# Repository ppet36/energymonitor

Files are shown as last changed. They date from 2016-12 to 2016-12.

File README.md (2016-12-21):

# Energy Monitor

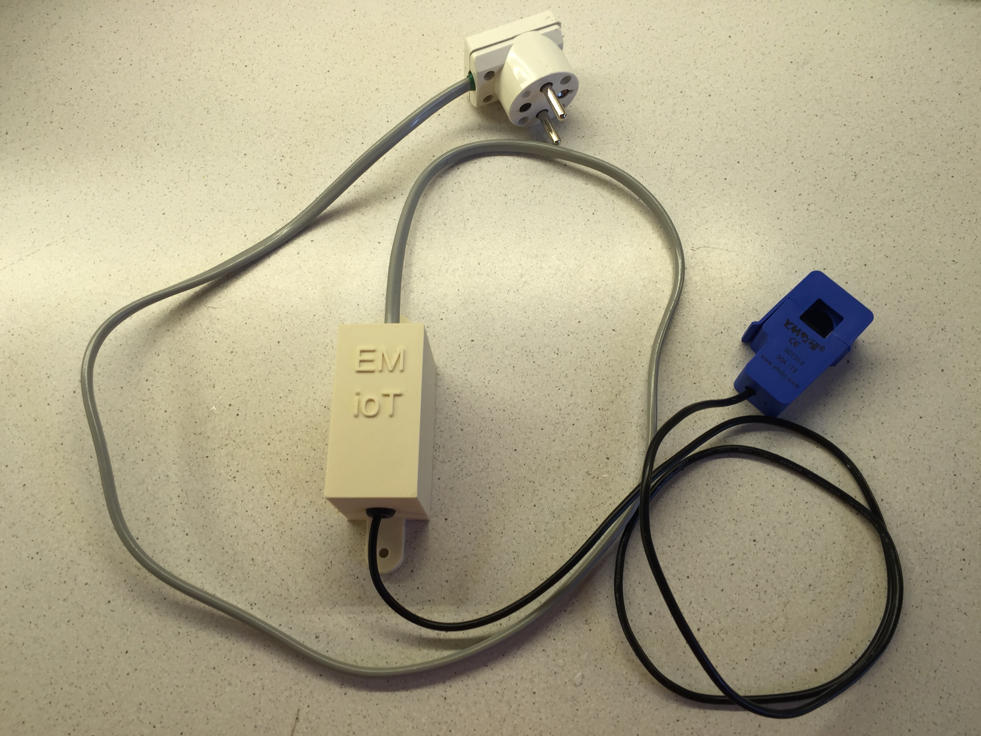
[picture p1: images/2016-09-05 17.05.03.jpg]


This repository encapsulates one phase energy monitor for ThingSpeak based on ESP8266-01 module, current transformer and precision rectifier.

Because ESP8266-01 has only two digital I/O pins (and also for resolution) is for A/D conversion used 18bit I2C A/D converter MCP3421 and fullwave precision rectifier realized via double operational amplifier LM258. For measuring current is used current transformer 30A SCT-013-030 which has already integrated shunt resistor.

For powering is used miniature 3.3V/600mA power supply from eBay such as http://www.ebay.com/itm/400761809788, but due to initial power requirements of ESP8266 i recomend 3.3V/1A power supply (which is also available through this seller).

Repository contains CadSoft's Eagle schematic and PCB layout. Because i do not have equipment for proper handling of SMDs (and also for use MCP3421 on breadboard) i created small DPS that holds MCP3421 and has standard DIP dimensions.
Note: Some 100n capacitors is soldered directly to pins on bottom side of PCB.

Software can be uploaded to ESP8266 via Arduino IDE. For building you need MCP342x module which is available here https://github.com/uChip/MCP342X on GitHub. For first 5 minutes after module startup is available WiFi AP "EnergyMonitor" with HTTP server at 192.168.4.1:80 behind it. On this URL is available simple configuration page for setting WiFi parameters, ThingSpeak channel/field with write-key, mains voltage and other tunning parameters. After 5 minutes, when the page is not accessed, module starts automatically. After module connects to configured WiFi is configuration server available on internal network at DHCP assigned IP address. Default parameters can be set in source file.

There are also OpenSCAD and STL model for enclosure.

I use module for several months at home and also on cottage. My public channels on ThingSpeak are:

https://thingspeak.com/channels/150525

https://thingspeak.com/channels/157732

Here are some project images:

### PCBs
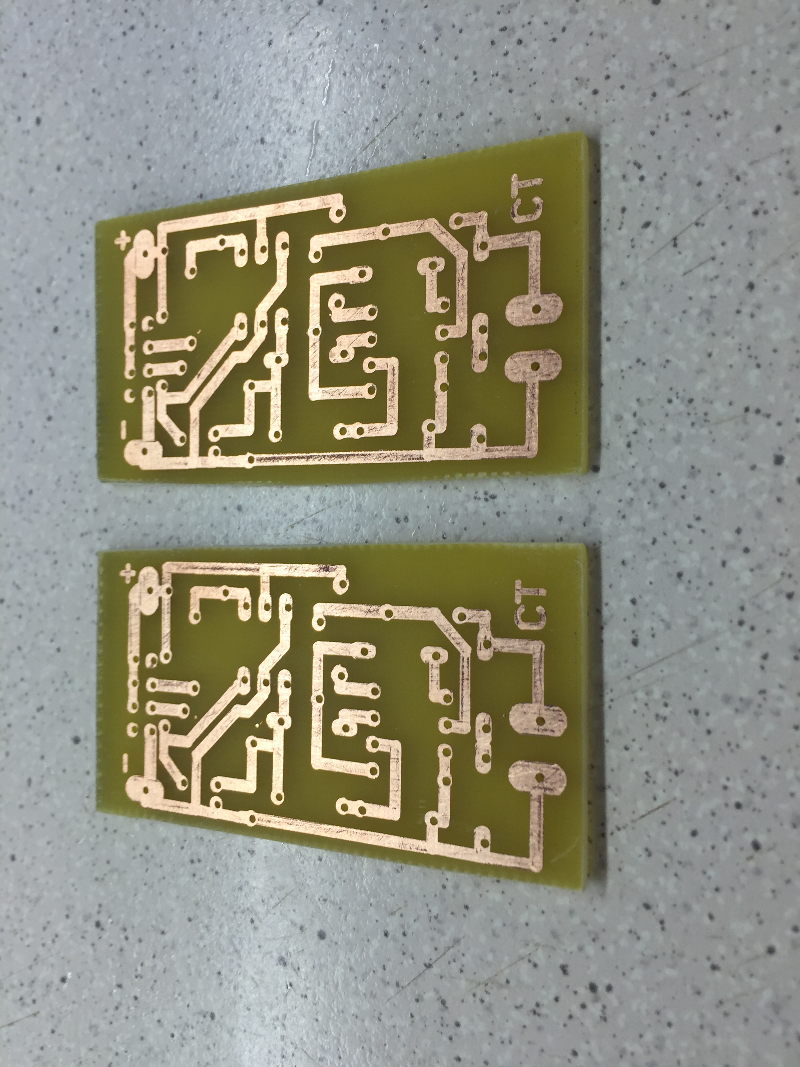
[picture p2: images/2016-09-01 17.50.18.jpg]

### Mounted PCB
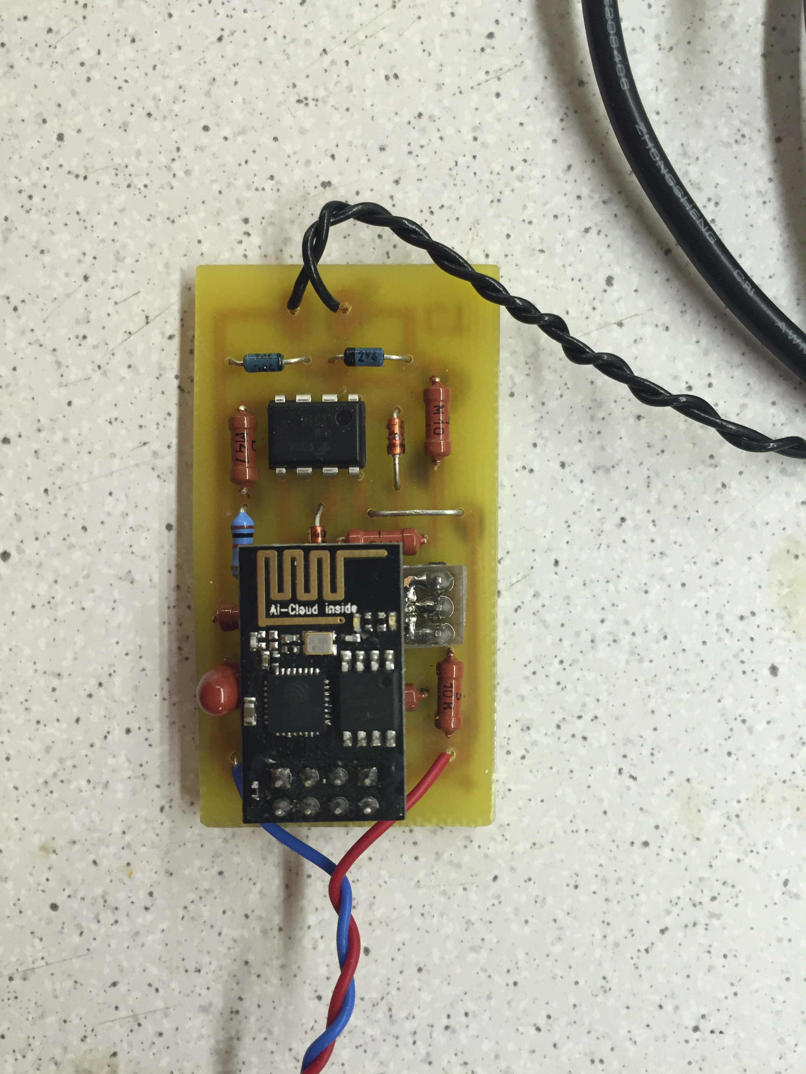
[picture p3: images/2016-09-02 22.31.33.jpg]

### 3D printed case
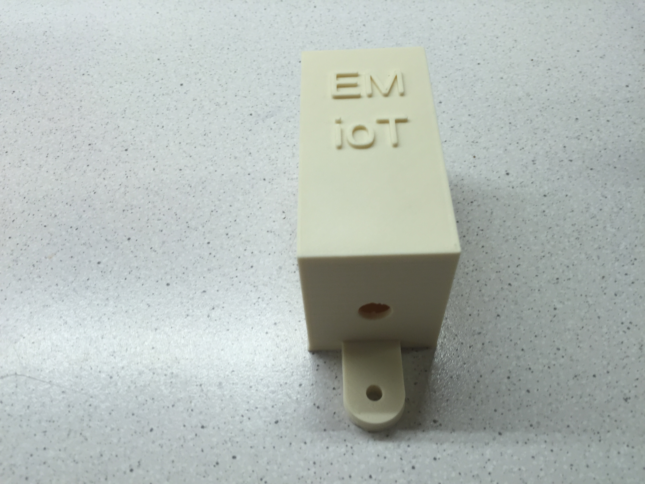
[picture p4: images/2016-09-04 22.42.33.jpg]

### MCP3421 breadboard modules
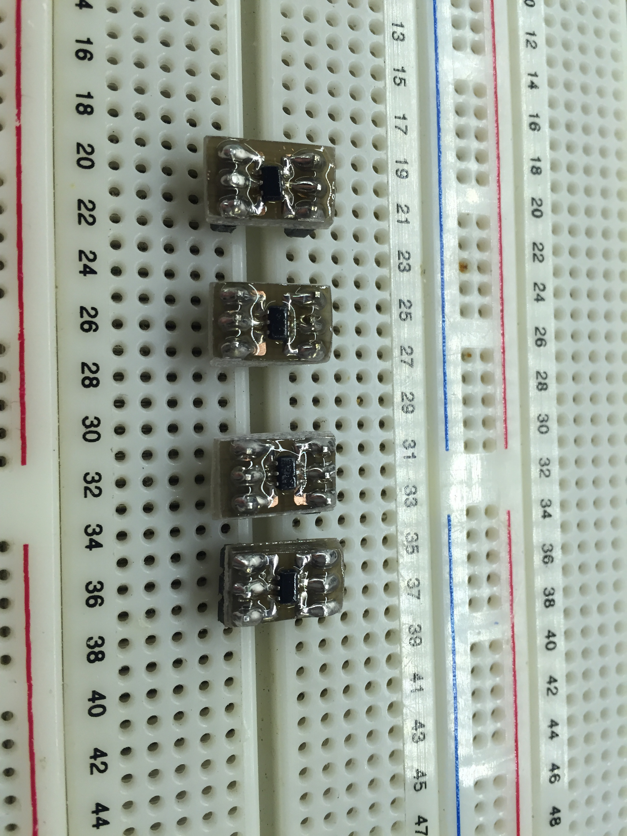
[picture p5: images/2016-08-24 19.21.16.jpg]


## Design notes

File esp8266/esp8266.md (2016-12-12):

ESP8266 software for uploading via Arduino IDE.

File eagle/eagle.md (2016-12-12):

This directory contains schematic, PCB layout for Eagle.

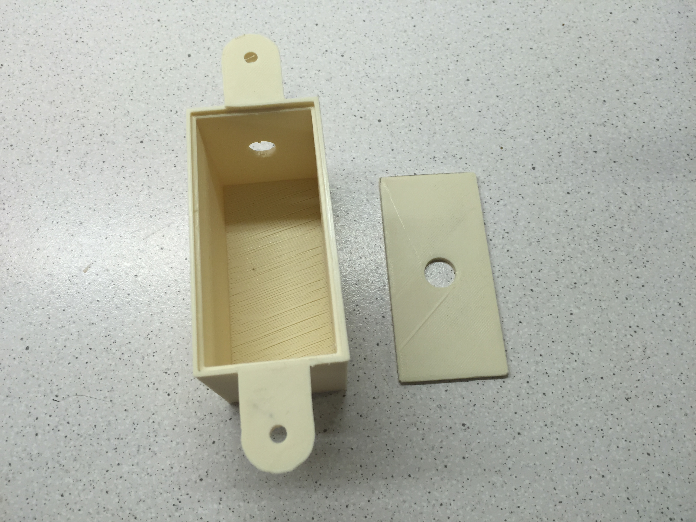
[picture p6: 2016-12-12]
images/2016-09-04 22.43.05.jpg

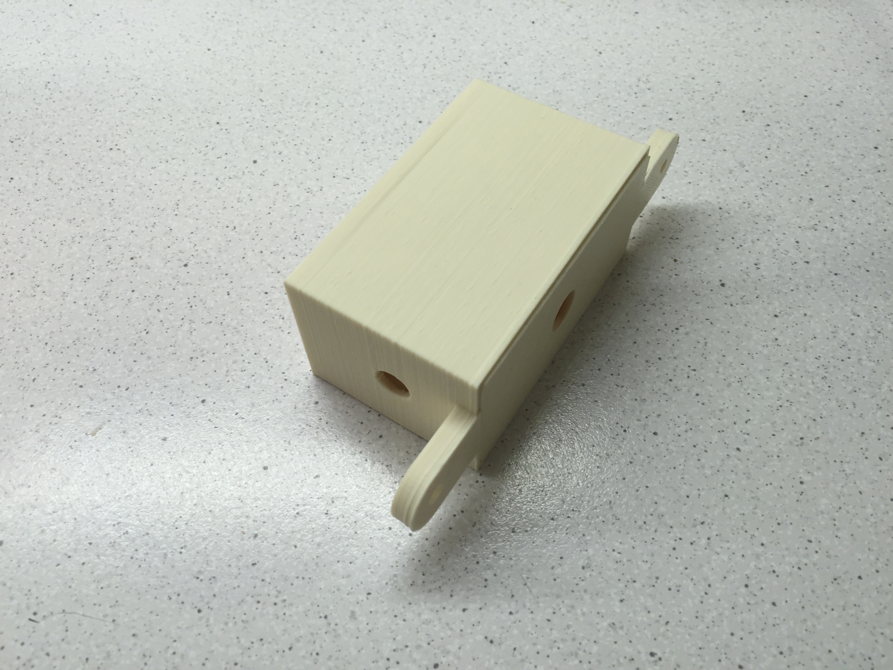
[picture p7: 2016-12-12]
images/2016-09-04 22.42.39.jpg

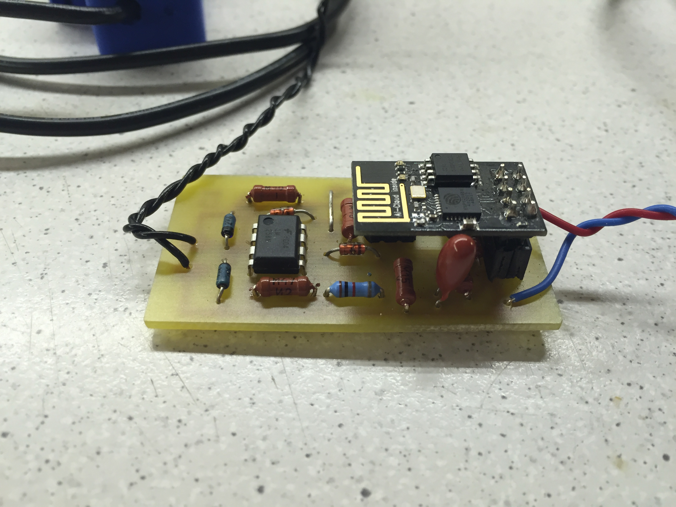
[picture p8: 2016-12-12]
images/2016-09-02 22.33.28.jpg

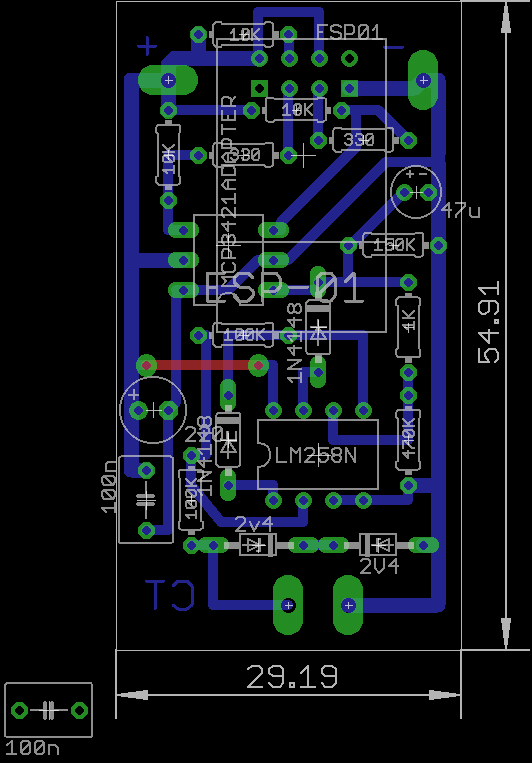
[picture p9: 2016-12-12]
eagle/energy_monitor_brd.png

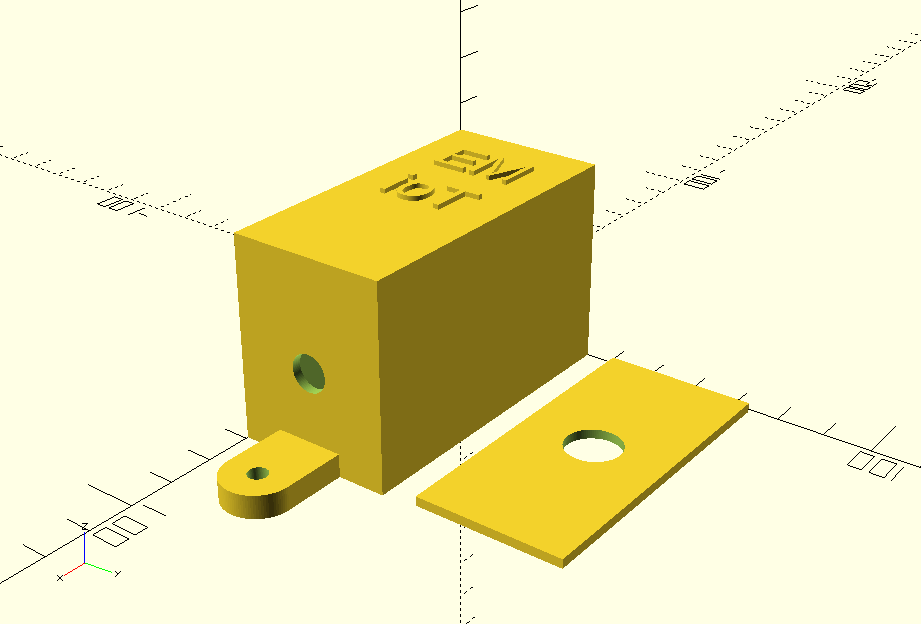
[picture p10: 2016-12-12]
openscad/case.png

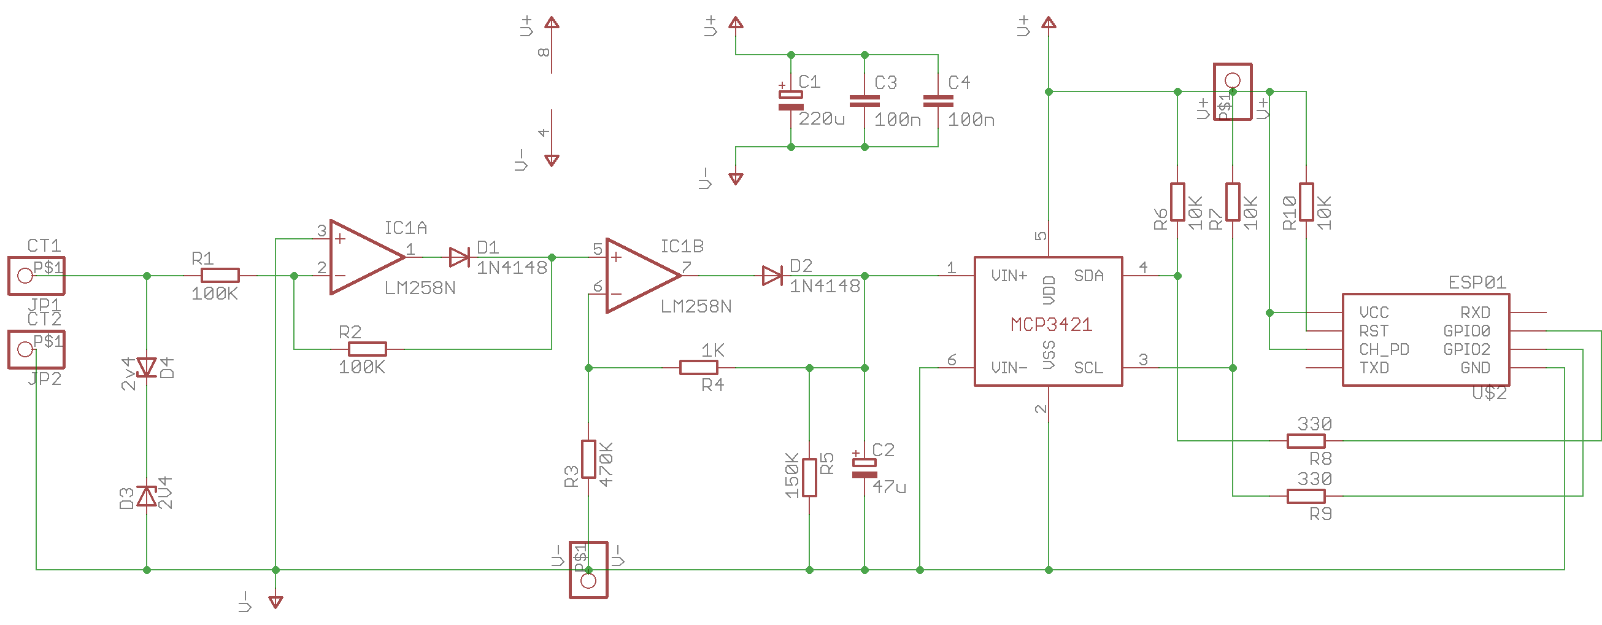
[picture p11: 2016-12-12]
eagle/energy_monitor_sch.png

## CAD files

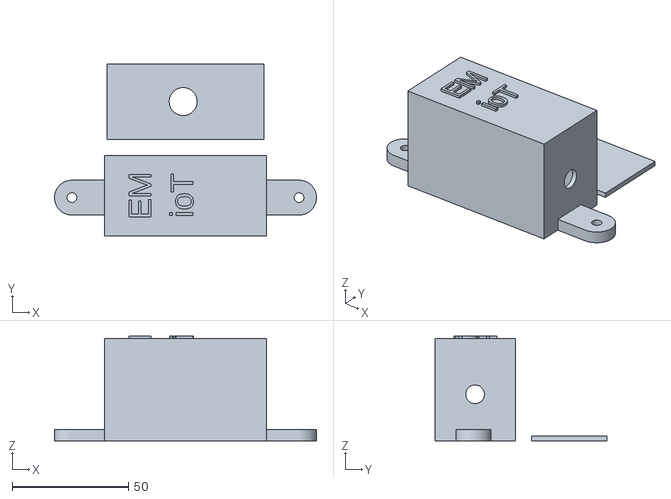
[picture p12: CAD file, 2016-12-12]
openscad/energy_monitor.stl
112.5 x 73.9 x 45.0

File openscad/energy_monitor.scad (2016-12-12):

innerWidth = 65.5;
innerHeight = 30.5;
innerDepth = 40;
thickness = 2;

$fn=100;

module box() {
  union() {
    difference() {
      cube ([innerWidth + 2*thickness, innerHeight+2*thickness, innerDepth + 2*thickness]);
      translate ([thickness,thickness,0]) cube ([innerWidth, innerHeight, innerDepth]);
      translate([innerWidth/2+thickness,(innerHeight+2*thickness)/2,(innerDepth/2)]) rotate([0,90,0]) cylinder (d=8,h=innerWidth+2*thickness,center=true);
    }
    
    color("red") translate([20,7,innerDepth+thickness]) rotate([0,0,90]) linear_extrude (height=3) text ("EM");
    color("red") translate([38,8,innerDepth+thickness]) rotate([0,0,90]) linear_extrude (height=3) text ("ioT");
  }
}

module ousko() {
  difference() {
    hull() {
      cylinder (d=15,h=5, center=true);
      translate([8,0,0]) cube ([15, 15, 5], center=true);
    }
    cylinder (d=4.2,h=5, center=true);
  }
}

module vrsek() {
  difference() {
    union() {
      box();
      translate ([-14,16.5,2.5]) ousko();
      translate ([innerWidth+14+thickness*2,16.5,2.5]) rotate ([0,0,180]) ousko();
    }
    vicko();
  }
}

module vicko() {
  color("green") {
    difference() {
      translate([thickness/2,thickness/2,0]) cube ([innerWidth + thickness-0.1, innerHeight+thickness-0.1, thickness]);
      translate([thickness/2+innerWidth/2,thickness/2+innerHeight/2+1,0])cylinder (d=12,h=thickness);
    }
  }
}

vrsek();
translate ([0,innerHeight+10,0]) vicko();

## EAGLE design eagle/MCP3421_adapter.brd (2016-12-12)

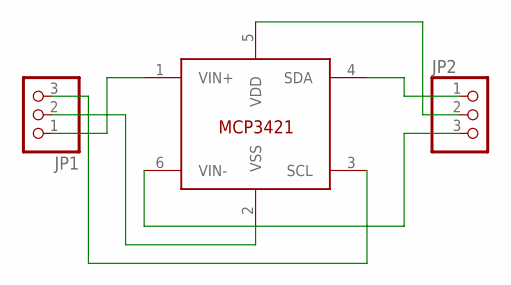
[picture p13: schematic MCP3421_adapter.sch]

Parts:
JP1, JP2: PINHD-1X3; 1X03
U$1: MCP3421; SOT23-6

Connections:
unnamed: JP1.1, U$1.1 (VIN+)
unnamed: JP1.2, U$1.2 (VSS)
unnamed: JP1.3, U$1.3 (SCL)
unnamed: JP2.1, U$1.4 (SDA)
unnamed: JP2.2, U$1.5 (VDD)
unnamed: JP2.3, U$1.6 (VIN-)

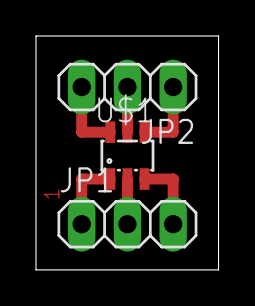
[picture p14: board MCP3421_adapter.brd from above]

Board: 2 copper layers, 10.1 x 13.0 mm, 3 parts (0 on the bottom side), 6 nets.

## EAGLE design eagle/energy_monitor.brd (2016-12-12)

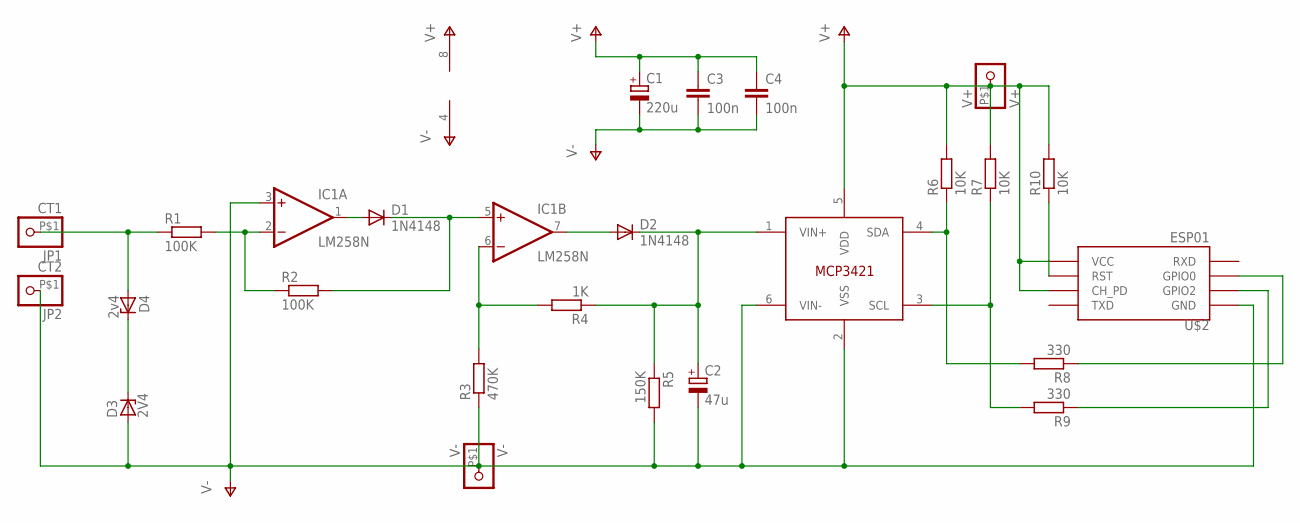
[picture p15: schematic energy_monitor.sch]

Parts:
C1: 220u; E2,5-6
C2: 47u; E2-4
C3, C4: 100n; C050-045X075
D1, D2: 1N4148; DO35-7
D3: 2V4; DO34Z7
D4: 2v4; DO34Z7
IC1: LM258N; DIL08
JP1: CT1; 1X1-BIGPOGO
JP2: CT2; 1X1-BIGPOGO
R1, R2: 100K; 0204/7
R3: 470K; 0204/7
R4: 1K; 0204/7
R5: 150K; 0204/7
R6, R7, R10: 10K; 0204/7
R8, R9: 330; 0204/7
U$1: MCP3421ADAPTER; DIL06
U$2: ESP01
V+: V+; 1X1-BIGPOGO
V-: V-; 1X1-BIGPOGO

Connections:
unnamed: D4.A, JP1.P$1, R1.1
unnamed: IC1.2 (-IN), R1.2, R2.1
unnamed: D1.A, IC1.1 (OUT)
unnamed: D1.C, IC1.5 (+IN), R2.2
unnamed: D3.C, D4.C
unnamed: D2.A, IC1.7 (OUT)
unnamed: C2.+, D2.C, R4.1, R5.1, U$1.1 (VIN+)
unnamed: IC1.6 (-IN), R3.2, R4.2
unnamed: R6.1, R8.2, U$1.4 (SDA)
unnamed: R7.1, R9.2, U$1.3 (SCL)
unnamed: R10.1, U$2.RST
unnamed: R8.1, U$2.GPIO0
unnamed: R9.1, U$2.GPIO2
V+: C1.+, C3.1, C4.1, IC1.8 (V+), R6.2, R7.2, R10.2, U$1.5 (VDD), U$2.CH_PD, U$2.VCC, V+.P$1
V-: C1.-, C2.-, C3.2, C4.2, D3.A, IC1.3 (+IN), IC1.4 (V-), JP2.P$1, R3.1, R5.2, U$1.2 (VSS), U$1.6 (VIN-), U$2.GND, V-.P$1

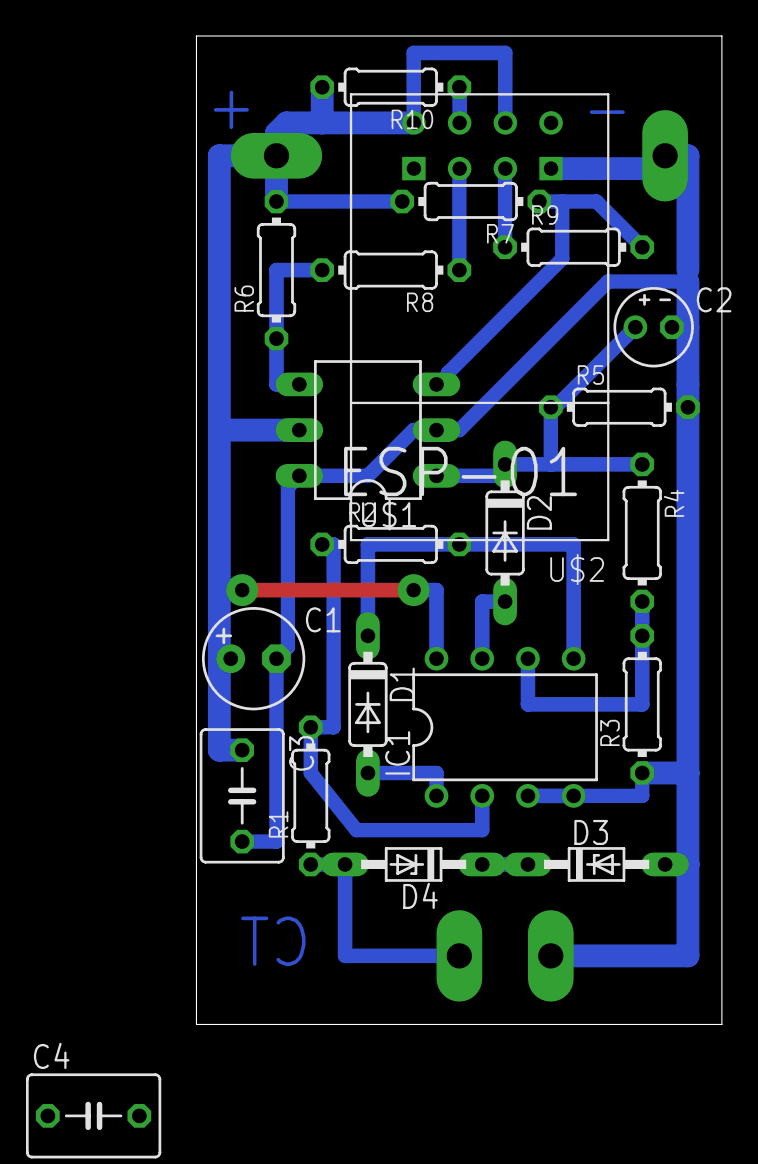
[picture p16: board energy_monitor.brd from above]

Board: 2 copper layers, 29.2 x 54.9 mm, 25 parts (0 on the bottom side), 15 nets.

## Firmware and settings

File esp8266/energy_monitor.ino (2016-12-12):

#include <Wire.h>
#include <MCP342x.h>
#include <EEPROM.h>
#include <ESP8266WiFi.h>
#include <ESP8266HTTPClient.h>
#include <WiFiClient.h>
#include <ESP8266WiFiMulti.h>
#include <ESP8266WebServer.h>

/**
 * One phase energy monitor based on ESP8266, MCP3421.
 * 
 * @author Pavel Petrzela
*/

// Magic, abych poznal, jestli jsem zapsal do EEPROM ja
#define MAGIC 0xA6

// Timeout konfigurace
#define CONFIG_TIMEOUT 1000 * 60 * 5

// Nazev WIFI AP
#define WIFI_AP_SSID "EnergyMonitorAP"

// Timeout A/D konverze
#define AD_TIMEOUT 2000

// Port WEB serveru konfigurace
#define WEB_SERVER_PORT 80

// Maximalni pocet vzorku do odeslani
#define MAX_SAMPLE_FREQUENCY 256

// Maximalni pocet radku v logu
#define MAX_LOG_LINES 50

// Maximalni index fieldu na ThingSpeak
#define TS_MAX_FIELD 8

// adresa MCP3421 A/D prevodniku
const uint8_t address = 0x68;

// Komunikacni objekt
MCP342x adc = MCP342x (address);

// Wifi
ESP8266WiFiMulti wifiMulti;

// Struktura do EEPROM
struct EmConfiguration {
  int magic;
  int sampleFrequency;
  char apName [24];
  char password [48];
  long voltage;
  long offset;
  long divider;
  char tsWriteKey [20];
  int tsFieldId;
};

// Nastaveni
EmConfiguration config;

// Server pro konfiguraci
ESP8266WebServer *server;

// Priznak, zdali byla spustena konfigurace
bool configExecuted = false;

// Posledni interakce s konfiguraci
long lastInteractionTime;

// Seznam radku logu
String logLines [MAX_LOG_LINES];
int logLinesIndex = 0;

// Posledni status
String lastStatus;

/**
 * Metoda je provedena pri inicializaci.
*/
void setup(void) {
  Serial.begin (115200);
  // Vypneme WiFi, aby se to nazacatek o nic nepokouselo
  WiFi.mode (WIFI_OFF);

  delay (10000);

  int i;
  for (i = 0; i < MAX_LOG_LINES; i++) {
    logLines [i] = "";
  }

  emLogLine ("setup()");

  // Komunikace po i2c sbernici na pinech 0 (sda) a 2 (scl)
  Wire.begin (0, 2);

  // Zkusime najit MCP3421
  do {
    emLogLine ("I2C reset...");
    // Reset sbernice
    MCP342x::generalCallReset();
    delay (10);

    emLogLine ("Searching MCP3421...");
  
    // Zjistime, zdali je MCP3421 na sbernici
    Wire.requestFrom (address, (uint8_t)1);
    if (!Wire.available()) {
      emLog ("No MCP3421 found at address ");
      emLogLine (String(address));
      delay (5000);
    } else {
      break;
    }
  } while (1);

  emLogLine ("MCP3421 found... reading configuration from EEPROM...");

  // nacteni konfigurace; pokud konfigurace jeste nebyla
  // vytvorena, tak se vymaze a inicializuje defaultnimi
  // hodnotami
  EEPROM.begin (sizeof (EmConfiguration));
  EEPROM.get (0, config);

  if (config.magic != MAGIC) {
    memset (&config, 0, sizeof (EmConfiguration));
    config.magic = MAGIC;
    config.sampleFrequency = 50;
    config.voltage = 230;
    config.offset = 523L;
    config.divider = 3805L;
    config.tsFieldId = 1;
    EEPROM.put (0, config);
  }
  
  EEPROM.end();

  emLog ("Configuration readed .. starting AP ");
  emLogLine (WIFI_AP_SSID);

  // Spustime konfiguracni AccessPoint pod nazvem EnergyMonitorAP
  WiFi.softAP (WIFI_AP_SSID);

  // ... a spustime HTTP server pro nastaveni; konfiguracni server
  // pobezi 5 minut od spusteni, pak 
  server = new ESP8266WebServer (WiFi.softAPIP(), WEB_SERVER_PORT);
  server->on ("/", wsHandleRoot);
  server->on ("/update", wsHandleUpdate);
  server->on ("/run", wsHandleRun);
  server->on ("/log", wsDisplayLog);
  server->on ("/getAdc", wsGetAdc);
  server->begin();

  emLog ("Started WebServer at ");
  emLog (ipToString (WiFi.softAPIP()));
  emLogLine (" port 80...");

  lastInteractionTime = millis();
  lastStatus = "";
}

/**
 * Prevede IP adresu do retezce.
*/
String ipToString (IPAddress myIP) {
  return String(myIP[0])+"."+String(myIP[1])+"."+String(myIP[2])+"."+String(myIP[3]);
}

/**
 * Prida radek do logu.
 * 
 * @param line radek.
*/
void emLogLine (String line) {
  if (logLinesIndex >= MAX_LOG_LINES - 1) {
    logLines [logLinesIndex] += line;
    
    int i;
    for (i = 1; i < MAX_LOG_LINES; i++) {
      logLines [i - 1] = logLines [i];
    }

    logLines [MAX_LOG_LINES - 1] = "";
  } else {
    logLines [logLinesIndex++] += line;
  }

  Serial.println (line);
}

/**
 * Pripoji retezec za posledni radek logu.
 * 
 * @param str retezec.
*/
void emLog (String str) {
  if (logLinesIndex >= MAX_LOG_LINES - 1) {
    logLines [MAX_LOG_LINES - 1] += str;
  } else {
    logLines [logLinesIndex] += str;
  }

  Serial.print (str);
}

/**
 * Aktualizuje retezcovou promennou v konfiguraci na zaklade
 * predaneho retezce.
 *
 * @param c promenna.
 * @param len maximalni delka.
 * @param val arduino string pro prevedeni.
*/
void updateConfigKey (char *c, int len, String val) {
  memset (c, 0, len);
  sprintf (c, "%s", val.c_str());
}

/**
 * Zapise koren http serveru; konfiguracni obrazovku.
*/
void wsHandleRoot() {
  String resp = "<html><head><title>Energy monitor configuration</title>";
  resp += "<meta name=\"viewport\" content=\"initial-scale=1.0, width = device-width, user-scalable = no\">";
  resp += "<script>";
  resp += "function ebi(s) {";
  resp += "return document.getElementById (s);";
  resp += "}\n";
  resp += "function updateAdc() {";
  resp += "var xhttp = new XMLHttpRequest();";
  resp += "xhttp.onreadystatechange = function() {";
  resp += "  if ((this.readyState == 4) && (this.status == 200)) {";
  resp += "    var adcVal = parseInt (this.responseText);";
  resp += "    var form = ebi('form');";
  resp += "    var voltage = parseInt (form.voltage.value);";
  resp += "    var offset = parseInt (form.offset.value);";
  resp += "    var divider = parseInt (form.divider.value);";
  resp += "    var current = ((adcVal - offset) / divider);";
  resp += "    if (current < 0) current = 0;";
  resp += "    var output = ebi('info');";
  resp += "    var s = 'ADC: <b>' + adcVal + '</b><br>POWER: <b>' + Number (voltage * current).toFixed (5) + 'W</b><br>MAX_POWER: <b>' + Number(voltage * ((131071 - offset) / divider)).toFixed (2) + 'W</b>';";
  resp += "    output.innerHTML = s;";
  resp += "    window.setTimeout(updateAdc, 1000);";
  resp += "  }";
  resp += "};";
  resp += "xhttp.open(\"GET\", \"/getAdc\", true);";
  resp += "xhttp.send();";
  resp += "}\n";
  resp += "function submitMode (mode) {";
  resp += "var f = ebi('form');";
  resp += "f.mode.value = mode;";
  resp += "f.submit();";
  resp += "}\n";
  resp += "</script>";
  resp += "</head><body>";
  resp += "<h1>Energy monitor configuration</h1>";
  resp += "<form method=\"post\" action=\"/update\" id=\"form\">";
  resp += "<input type=\"hidden\" name=\"mode\" value=\"save\">";
  resp += "<table border=\"0\" cellspacing=\"0\" cellpadding=\"5\">";
  resp += "<tr><td>AP SSID:</td><td><input type=\"text\" name=\"apName\" value=\"" + String(config.apName) + "\" maxlength=\"24\"></td><td></td></tr>";
  resp += "<tr><td>AP Password:</td><td><input type=\"password\" name=\"password\" value=\"" + String(config.password) + "\" maxlength=\"48\"></td><td></td></tr>";
  resp += "<tr><td>Voltage:</td><td><input type=\"text\" name=\"voltage\" value=\"" + String(config.voltage) + "\"></td><td></td></tr>";
  resp += "<tr><td>Offset:</td><td><input type=\"text\" name=\"offset\" value=\"" + String(config.offset) + "\"></td><td><input type=\"button\" onclick=\"submitMode('calibrate');\" value=\"Calibrate\"/></td></tr>";
  resp += "<tr><td>Divider:</td><td><input type=\"text\" name=\"divider\" value=\"" + String(config.divider) + "\"></td><td></td></tr>";
  resp += "<tr><td>ThingSpeak key:</td><td><input type=\"text\" name=\"tsWriteKey\" value=\"" + String(config.tsWriteKey) + "\" maxlength=\"16\"></td><td></td></tr>";
  resp += "<tr><td>ThingSpeak field:</td><td><input type=\"text\" name=\"tsFieldId\" value=\"" + String(config.tsFieldId) + "\" maxlength=\"1\"></td><td></td></tr>";
  resp += "<tr><td>Sample frequency:</td><td><input type=\"text\" name=\"sampleFrequency\" value=\"" + String(config.sampleFrequency) + "\"></td><td></td></tr>";
  resp += "<tr><td colspan=\"3\" align=\"center\"><input type=\"submit\"></td></tr>";
  resp += "</table></form>";
  resp += "<code id=\"info\"></code>";
  resp += "<p><a href=\"/log\">Last " + String(MAX_LOG_LINES) + " log lines</a></p>";
  if (!configExecuted) {
    resp += "<p><a href=\"/run\">Start monitoring</a></p>";
  }
  resp += "<script>window.setTimeout(updateAdc, 1000);</script></body></html>";

  server->send(200, "text/html", resp);

  lastInteractionTime = millis();
}

/**
 * Aktualizace nastaveni.
*/
void wsHandleUpdate() {
  emLogLine ("handleUpdate()");
  yield();
  String mode = server->arg("mode");
  String apName = server->arg ("apName");
  String password = server->arg ("password");
  long voltage = atol (server->arg ("voltage").c_str());
  long offset = atol (server->arg ("offset").c_str());
  long divider = atol (server->arg ("divider").c_str());
  String tsWriteKey = server->arg ("tsWriteKey");
  int tsFieldId = atoi (server->arg ("tsFieldId").c_str());
  int sampleFrequency = atoi (server->arg ("sampleFrequency").c_str());

  emLog ("mode="); emLogLine (mode);
  emLog ("apName="); emLogLine (apName);
  emLog ("password="); emLogLine (password);
  emLog ("voltage="); emLogLine (String(voltage));
  emLog ("offset="); emLogLine (String(offset));
  emLog ("divider="); emLogLine (String(divider));
  emLog ("tsWriteKey="); emLogLine (tsWriteKey);
  emLog ("tsFieldId="); emLogLine (String(tsFieldId));
  emLog ("sampleFrequency="); emLogLine (String(sampleFrequency));

  // pojistka proti nacteni jinak nez postem
  if (apName.length() > 1) {
    if (mode == "save") {
      // aktualizujeme konfiguraci
      updateConfigKey (config.apName, 24, apName);
      updateConfigKey (config.password, 48, password);
      config.voltage = voltage;
      config.offset = offset;
      config.divider = divider;
      updateConfigKey (config.tsWriteKey, 16, tsWriteKey);
      config.tsFieldId = constrain (tsFieldId, 1, TS_MAX_FIELD);
      config.sampleFrequency = constrain (sampleFrequency, 1, MAX_SAMPLE_FREQUENCY);
  
      // zapiseme do EEPROM
      EEPROM.begin (sizeof (EmConfiguration));
      EEPROM.put (0, config);
      EEPROM.end();
  
      String resp = "<script>window.alert ('Configuration updated...'); window.location.replace ('/');</script>";
      server->send (200, "text/html", resp);
    } else if (mode == "calibrate") {
      wsCalibrateOffset();
    }
  } else {
    server->send (200, "text/html", "");
  }

  lastInteractionTime = millis();
}

/**
 * Spusteni monitorovani. 
*/
void wsHandleRun() {
  configExecuted = true;

  String resp = "<script>window.alert ('Monitoring started...'); window.location.replace ('/');</script>";
  server->send (200, "text/html", resp);

  lastInteractionTime = millis();
}

/**
 * Kalibrace offsetu.
*/
void wsCalibrateOffset() {
  String result = "";
  int sample;
  long maxVal = 0L;

  for (sample = 1; sample < 60; sample++) {
    long value = getAdc();

    if (value > maxVal) {
      maxVal = value;
    }

    delay (500);
    yield();
  }

  config.offset = maxVal;

  String resp = "<script>window.location.replace('/');</script>";
  server->send (200, "text/html", resp);

  lastInteractionTime = millis();
}

/**
 * Zobrazeni logu.
*/
void wsDisplayLog() {
  String resp = "<html><head><title>Last " + String (MAX_LOG_LINES) + "</title>";
  resp += "</head><body><h1>Last " + String (MAX_LOG_LINES) + " log lines</h1><pre>";
  int i;
  for (i = 0; i <= logLinesIndex; i++) {
    resp += logLines [i] + "<br>";
  }
  resp += "</pre></body></html>";

  server->send (200, "text/html", resp);
  
  lastInteractionTime = millis();
}

/**
 * Aktualni hodnota z MCP3421.
*/
void wsGetAdc() {
  String resp (getAdc());
  server->send (200, "text/plain", resp);
  
  lastInteractionTime = millis();  
}

/**
 * Metoda vraci prevedenou hodnotu z MCP3421.
 * 
 * @return long hodnota.
*/
long getAdc() {
  long value = 0;
  MCP342x::Config status;
  
  uint8_t err = adc.convertAndRead (MCP342x::channel1, MCP342x::continous, MCP342x::resolution18, MCP342x::gain2, AD_TIMEOUT, value, status);
    
  if (err) {
    emLog ("Convert error: ");
    emLog (String(err));
    emLogLine ("!");
    return -1L;
  } else {
    return value;
  }
}

/**
 * Zakodovani parametru URL.
 * 
 * @param str retezec.
 * @return String zakodovany.
*/
String urlencode (String str) {
  String encodedString="";
  char c;
  char code0;
  char code1;
  for (int i =0; i < str.length(); i++){
    c=str.charAt(i);
    if (c == ' '){
      encodedString+= '+';
    } else if (isalnum(c)){
      encodedString+=c;
    } else{
      code1=(c & 0xf)+'0';
      if ((c & 0xf) >9){
        code1=(c & 0xf) - 10 + 'A';
      }
      c=(c>>4)&0xf;
      code0=c+'0';
      if (c > 9){
        code0=c - 10 + 'A';
      }
      encodedString+='%';
      encodedString+=code0;
      encodedString+=code1;
    }
    yield();
  }
  return encodedString;
}

/**
 * Odpoji a sjedna spojeni na WiFi.
*/
void reconnectWifi() {
  // zavreme HTTP server a spustime WiFi pouze v modu klienta tj. zrusime access point
  server->close();
  
  delay (1000);
  WiFi.disconnect();
  delay (2000);
  WiFi.mode (WIFI_STA);
  delay (2000);
  
  // pridame nastavenou WiFinu; jinak to pojede na jakekoliv verejne, ale vybere to
  // tu nejsilnejsi
  emLog ("Connecting to WiFi ");
  emLog (config.apName);
  
  wifiMulti.addAP (config.apName, config.password);
  delay (5000);
  while (wifiMulti.run() != WL_CONNECTED) {
    yield();
    delay(1000);
    emLog (".");
  }
  emLogLine("");

  emLogLine ("WiFi connected...");

  server = new ESP8266WebServer (WiFi.localIP(), WEB_SERVER_PORT);
  server->on ("/", wsHandleRoot);
  server->on ("/update", wsHandleUpdate);
  server->on ("/run", wsHandleRun);
  server->on ("/log", wsDisplayLog);
  server->on ("/getAdc", wsGetAdc);
  server->begin();
  emLog ("Started WebServer at ");
  emLog (ipToString (WiFi.localIP()));
  emLogLine (" port 80...");
}

/**
 * Smycka monitorovani spotreby a odesilani na ThingSpeak.
*/
void thingSpeakLoop() {
  emLog ("Config timeout expired ... closing ");
  emLog (WIFI_AP_SSID);
  emLogLine (" and starting monitoring...");

  reconnectWifi();

  // buffer pro prumerovani hodnot
  long buffer [MAX_SAMPLE_FREQUENCY];
  int bufferPos = 0;
  int errorCount = 0;

  while (true) {
    // Obsluha HTTP
    server->handleClient();
    
    // nacteme hodnotu z MCP3421
    long value = getAdc();
    if (value >= 0L) {
      // ulozime hodnotu na dalsi pozici v bufferu
      buffer [bufferPos] = value;
      bufferPos++;

      if (bufferPos >= config.sampleFrequency) {
        bufferPos = 0;

        // pokud je buffer zaplnen, vypocitame prumernou hodnotu
        unsigned long average = 0L;
        for (int i = 0; i < config.sampleFrequency; i++) {
          long val = buffer [i] - config.offset;
          if (val >= 0L) {
            average += val;
          }
        }
        average /= config.sampleFrequency;

        // vypocitame proud a vykon
        double current = double(average) / double(config.divider);
        double power = current * double(config.voltage);

        char number [20];
        dtostrf (current, 5, 6, number);
 
        emLog (number);
        emLog ("A, ");
  
        dtostrf (power, 5, 3, number);
  
        emLog (number);
        emLog ("W -> ");

        if (strlen (config.tsWriteKey) < 1) {
          emLogLine ("ThingSpeak write key is not set!");
        } else if (wifiMulti.run() == WL_CONNECTED) {
          // pokud mame spojeni na WiFi, aktualizujeme ThingSpeak
          HTTPClient http;

          String stat = "OK; WebServer listening at " + ipToString (WiFi.localIP()) + ":" + String(WEB_SERVER_PORT);
          String statStr;
          if (stat == lastStatus) {
            statStr = "";
          } else {
            statStr = "&status=" + urlencode (stat); 
          }

          String sNumber (number);
          sNumber.trim();
  
          char url [512];
          sprintf (url, "http://api.thingspeak.com/update.json?field%d=%s%s&api_key=%s", config.tsFieldId, sNumber.c_str(), statStr.c_str(), config.tsWriteKey);
  
          http.begin (url);
  
          int httpCode = http.GET();
          if (httpCode == HTTP_CODE_OK) {
            emLog ("-> ");
            emLog (url);
            emLogLine (" -> [HTTP] UPDATE OK");

            lastStatus = stat;
            errorCount = 0;
          } else {
            emLog ("[HTTP] GET... failed, error(");
            emLog (String(httpCode));
            emLog ("): url=");
            emLog (url);
            emLog (" -> ");
            emLogLine (http.errorToString(httpCode));
            errorCount++;
          }
  
          http.end();
        } else {
          emLogLine ("WiFi NOT CONNECTED");
          errorCount++;
        }
      }
    }

    if (errorCount > 30) {
      emLogLine ("ErrorCount > 30; reconnecting WiFi...");
      errorCount = 0;
      reconnectWifi();
    }
  
    // dame prostor procesum na pozadi
    yield();
  }
}

/**
 * Periodicky vykonavana metoda. 
*/
void loop (void) {
  if (configExecuted) {
    thingSpeakLoop();
  } else {
    boolean configValid = (strlen (config.tsWriteKey) > 0) && (strlen (config.apName) > 0);

    if (!configValid || (millis() - lastInteractionTime < CONFIG_TIMEOUT)) {
      server->handleClient();
    } else {
      configExecuted = true; 
    }
  }
}
